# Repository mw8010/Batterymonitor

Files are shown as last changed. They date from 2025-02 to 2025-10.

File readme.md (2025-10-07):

# Battery Monitor with INA226 and SenseESP

## Overview
This project is a DIY battery monitor for our trawler. It uses an ESP32 to measure current, voltage, and power with the INA226 sensor. The collected data is integrated into Signal K via SenseESP. Additionally, a OneWire temperature sensor is used to monitor battery temperature.

## Why Low-Side Current Sensing?

Low-side current sensing means placing the shunt resistor between the negative battery terminal and ground (system GND). This method is recommended for higher battery voltages (e.g. 48V), as it keeps the INA226 within its voltage specifications and avoids damage or incorrect measurements.

**Advantages:**
- The INA226 always operates within its safe voltage range (max. 36V common-mode).
- Simple and safe wiring for most installations (vehicles, boats).
- No need for a voltage divider at the INA226 input.

**Note:**  
The measured current may have an inverted sign. This is corrected in the software.

## What is Signal K?
[Signal K](https://signalk.org/) is an open data format for marine electronics. It enables the integration and exchange of sensor data between various devices and applications on board a boat.

## What is SenseESP?
[SenseESP](https://github.com/SignalK/SensESP) is an open-source framework that simplifies the development of sensors that transmit their data to a Signal K server via Wi-Fi. It is based on the ESP32 and uses a modular architecture for flexible customization.

## Features
- Measurement of battery voltage, current, and power with INA226
- Calculation of the state of charge (SoC) based on battery type and voltage
- Calculation of remaining amp-hours (Ah) and estimated runtime
- Configurable battery parameters via the SenseESP web UI
- Alarm notifications for shunt overvoltage, bus overvoltage, and power limits
- Temperature monitoring via a OneWire sensor (e.g., DS18B20)

## Hardware Requirements
- **ESP32 D1 Mini** – Microcontroller
- **INA226 CJMCU** – Current sensor
- **DS18B20** – Temperature sensor
- **3A Mini DC-DC Buck Step Down Converter** – Voltage converter
- **Shunt resistor** – For current measurement (adapted to the maximum current)

## Terminal Assignments
| Terminal | Label | Description |
|---|---|---|
| **U1** | Power IN | + / - (6 - 48V) |
| **U2** | Temperature Sensor | + / - / Data |
| **U4** | INA226 | VBUS / IN- / IN+ |

## Signal K Data Points
- `electrical.batteries.<battery_name>.voltage` – Battery voltage in V
- `electrical.batteries.<battery_name>.current` – Battery current in A
- `electrical.batteries.<battery_name>.power` – Battery power in W
- `electrical.batteries.<battery_name>.stateOfCharge` – State of charge in % (coulomb counting)
- `electrical.batteries.<battery_name>.stateOfCharge_voltageSoC` – State of charge based on voltage in %
- `electrical.batteries.<battery_name>.ampHours` – Remaining Ah
- `electrical.batteries.<battery_name>.timeToGo` – Remaining time in seconds
- `electrical.batteries.<battery_name>.temperature` – Battery temperature in °K
- `electrical.batteries.<battery_name>.alerts.shuntOverVoltage` – Alarm for shunt overvoltage
- `electrical.batteries.<battery_name>.alerts.busOverVoltage` – Alarm for bus overvoltage
- `electrical.batteries.<battery_name>.alerts.powerOverLimit` – Alarm for power limit exceeded

## Installation
### 1. Preparation
- Install PlatformIO (recommended)
  - [PlatformIO IDE for VSCode](https://platformio.org/install/ide?install=vscode)
  - [PlatformIO IDE for Atom](https://platformio.org/install/ide?install=atom)
  - [PlatformIO Core (CLI)](https://docs.platformio.org/en/latest/core/installation.html)
- Install required libraries:
  - [SignalK/SenseESP](https://github.com/SignalK/SensESP)
  - [sensesp/OneWire](https://github.com/PaulStoffregen/OneWire)
  - [INA226](https://github.com/RobTillaart/INA226)

### 2. Clone the repository
- Clone or download this repository to your local machine:
  ```sh
  git clone https://github.com/mw8010/Batteriemonitor.git
  cd Batteriemonitor
  ```

### 3. Upload the code
Open the project in PlatformIO.
Upload the code to your ESP32.

### 4. Configure SenseESP
After the first start, the ESP32 will open an access point.
Connect to the network and enter the Wi-Fi credentials (Wi-Fi password: thisisfine).
Use the SenseESP web UI to configure the battery (see Configuration) and connect the ESP32 to the network where the Signal K server is running.
The data should now appear on the Signal K server under the configured paths.

## Configuration
The following parameters can be adjusted via the SenseESP web UI:
- Battery type (LiFePO4, AGM, Gel, Lead-Acid)
- Battery voltage (12V, 24V, 48V (LiFePO4 only))
- Battery capacity in Ah
- Maximum shunt current
- Shunt voltage in mV
- Battery name for Signal K

**After each configuration change, the ESP32 must be restarted.**

## Usage
- Once set up, the ESP32 continuously transmits measurement values to Signal K.
- Configuration changes can be made via the web UI.
- Alarm notifications are triggered when defined thresholds are exceeded.

### Hardware Installation Notes
**Shunt Resistor (Low-Side Measurement)**

- The shunt resistor must be installed between the negative battery terminal and the system ground (GND).
- Connect the negative battery terminal to one end of the shunt resistor.
- Connect the other end of the shunt resistor to the system ground (GND).
- All consumers and the ESP32 remain connected to system ground as usual.
- Ensure that all connections are tight and secure to ensure accurate measurements.

**INA226 Sensor (Low-Side Wiring)**

- Connect the INA226 sensor to the shunt resistor according to the schematic:
  - `IN+` of the INA226 to the end of the shunt connected to the negative battery terminal.
  - `IN-` of the INA226 to the end of the shunt connected to system ground (GND).
  - `VBUS` connected to system ground (GND).
- Connect the INA226 sensor to the ESP32 according to the schematic.

**ESP32**

- Connect the ESP32 to the INA226 sensor and the OneWire temperature sensor according to the schematic.
- Ensure that the ESP32 is properly powered (e.g., via a DC-DC Buck Step Down Converter).

**PCB**

- To facilitate the connection of the components, you can use the Gerber files in the gerber folder to order a suitable PCB.

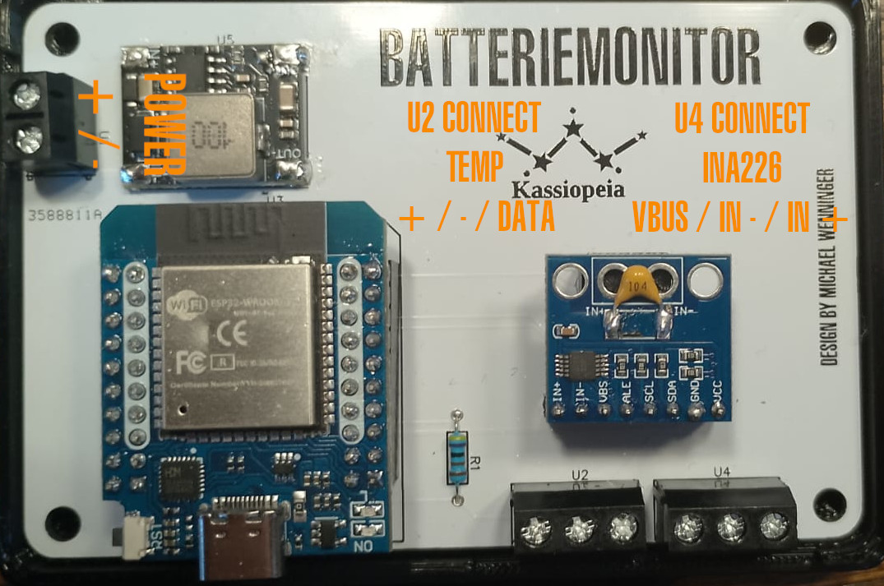
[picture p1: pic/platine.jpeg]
PCB


### Enclosure

In the `/3d-files` folder, you will find STEP files for a suitable enclosure that you can print to protect and mount the finished PCB.

## Used Components
- [ESP32 D1 Mini](https://de.aliexpress.com/item/1005006267267848.html)
- [INA226 CJMCU](https://de.aliexpress.com/item/1005001972537281.html)
- [3A Mini DC-DC Buck Step Down Converter](https://de.aliexpress.com/item/1005005505907937.html)
- [DS18B20 Temperature Sensor](https://de.aliexpress.com/item/1005005488542048.html)

## Repository Files
- **`/gerber`** – Contains Gerber files for the PCB.
- **`/schematic`** – Contains the circuit diagram.
- **`/3d-files`** – Contains the STEP files for a suitable enclosure.

## License
- **Software:** [GNU General Public License v3.0](license.md)  
- **Hardware:** [CERN Open Hardware Licence v2 - Strongly Reciprocal](license.md)

## Acknowledgments
This project is based on the [Battery Monitor Project by Techstyleuk](https://github.com/Techstyleuk/SensESP_3_Battery_Monitor).

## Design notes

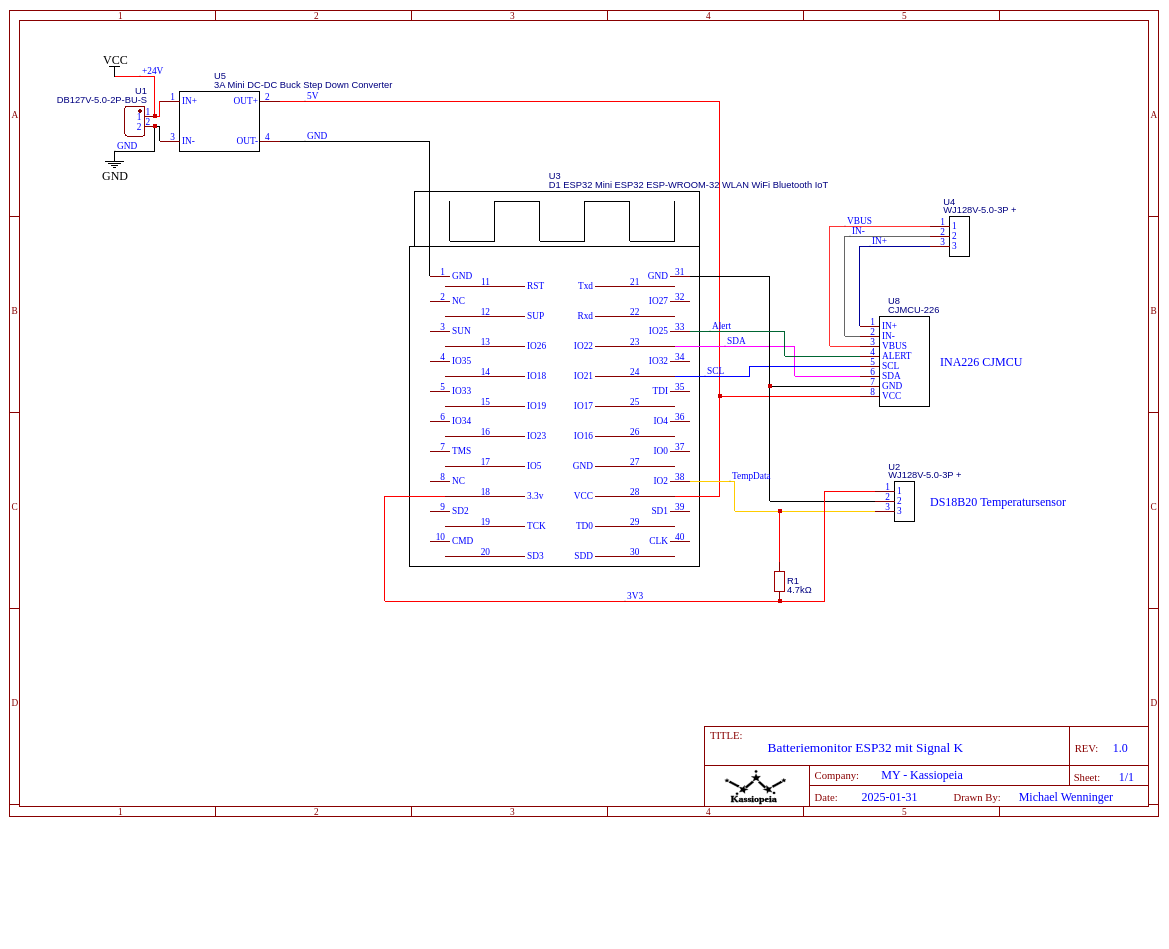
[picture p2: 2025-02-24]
schaltplan/Schematic_Batteriemonitor_2025-02-23.png

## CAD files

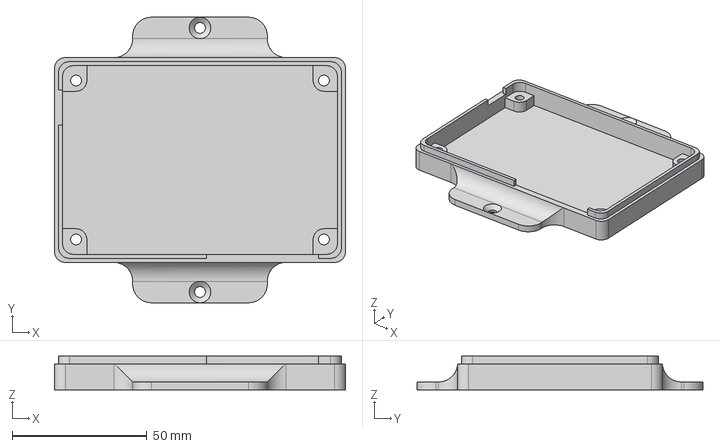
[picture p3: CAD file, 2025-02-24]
3d-files/Boden.step
108.0 x 106.0 x 12.6 mm

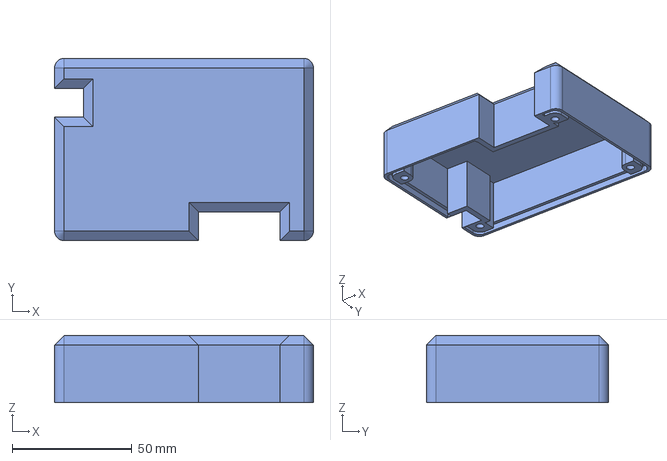
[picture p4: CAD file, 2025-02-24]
3d-files/Deckel.step
108.0 x 76.0 x 28.0 mm

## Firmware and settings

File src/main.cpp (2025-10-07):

#include <Arduino.h>
#include <memory>
#include "sensesp/signalk/signalk_output.h"
#include "sensesp/transforms/linear.h"
#include "sensesp/transforms/curveinterpolator.h"
#include "sensesp/ui/config_item.h"
#include "sensesp/ui/ui_controls.h"
#include "sensesp_app_builder.h"
#include "sensesp_onewire/onewire_temperature.h"
#include "sensesp/signalk/signalk_metadata.h"
#include "INA226.h"

using namespace sensesp;
using namespace sensesp::onewire;

// Setze die INA226-Adresse
INA226 INA0(0x40);

// Setze Wifi-Netzwerkdaten
const char* hostname = "BatteryShuntESP";

// Variable Temperatursensor
uint8_t pin = 2; // Pin, an dem der Temperatursensor angeschlossen ist

// Abfrageintervall für die Sensoren
uint read_delay = 1000; // Zeit zwischen den Messungen

// Globale Variablen für Batterietyp, Spannung und AH
String battery_type = "LiFePO4"; // Standardtyp der Batterie
String battery_type_config_path = "/config/battery_type";
float battery_voltage = 12; // Standardspannung der Batterie in V
String battery_voltage_config_path = "/config/battery_voltage";
float battery_capacity = 100; // Standardkapazität der Batterie in Ah
String battery_capacity_config_path = "/config/battery_ah";

// Konfigurationspfade für den INA226
float max_current = 500.0; // Maximalstrom in A
String max_current_config_path = "/config/max_current";
float shunt_voltage = 75.0; // Shunt-Spannung in mV
String shunt_voltage_config_path = "/config/shunt_voltage";
float shunt_resistance; // Shunt-Widerstand in Ohm (Wert wird berechnet)
String shunt_resistance_config_path = "/config/shunt_resistance";

// Definiere Variable für den Batterienamen
String battery_name = "Battery1"; // Standardname für die Batterie
String battery_name_config_path = "/config/battery_name";

// Erstelle den vollständigen SignalK Pfad durch Konkatenation
String sk_path_current = "electrical.batteries." + battery_name + ".current";
String sk_path_voltage = "electrical.batteries." + battery_name + ".voltage";
String sk_path_power = "electrical.batteries." + battery_name + ".power";
String sk_path_soc = "electrical.batteries." + battery_name + ".stateOfCharge";
String sk_path_ah = "electrical.batteries." + battery_name + ".ampHours";
String sk_path_time_to_go = "electrical.batteries." + battery_name + ".timeToGo";
String sk_path_shunt_over_voltage = "electrical.batteries." + battery_name + ".alerts.shuntOverVoltage";
String sk_path_bus_over_voltage = "electrical.batteries." + battery_name + ".alerts.busOverVoltage";
String sk_path_power_over_limit = "electrical.batteries." + battery_name + ".alerts.powerOverLimit";
String temp_one_wire_path = "/Battery Temperature/" + battery_name + "/oneWire";
String temp_linear_path = "/Battery Temperature/" + battery_name + "/linear";
String temp_sk_path = "electrical.batteries." + battery_name + ".temperature";

//Definiere die Metadaten für die SignalK-Objekte
SKMetadata* metadata_current = new SKMetadata("A", "Current", "Current of the battery", "A");
SKMetadata* metadata_voltage = new SKMetadata("V", "Voltage", "Voltage of the battery", "V");
SKMetadata* metadata_power = new SKMetadata("W", "Power", "Power of the battery", "W");
SKMetadata* metadata_soc = new SKMetadata("%", "State of Charge", "State of Charge of the battery", "%");
SKMetadata* metadata_ah = new SKMetadata("Ah", "Ampere Hours", "Ampere Hours used of the battery", "Ah");
SKMetadata* metadata_time_to_go = new SKMetadata("s", "Time to Go", "Time to go of the battery", "s");
SKMetadata* metadata_shunt_over_voltage = new SKMetadata("Alert", "Shunt Over Voltage", "Shunt Over Voltage Alert", "Alert");
SKMetadata* metadata_bus_over_voltage = new SKMetadata("Alert", "Bus Over Voltage", "Bus Over Voltage Alert", "Alert");
SKMetadata* metadata_power_over_limit = new SKMetadata("Alert", "Power Over Limit", "Power Over Limit Alert", "Alert");
SKMetadata* metadata_temp = new SKMetadata("K", "Temperature", "Temperature of the battery", "K");

// Definiere Variablen für die Alarmmeldungen
SKOutputString* alert_shunt_over_voltage;
SKOutputString* alert_bus_over_voltage;
SKOutputString* alert_power_over_limit;

// Variable für verbrauchte Amperestunden
float amp_hours_used = 0.0;

// Berechne den Shunt-Widerstand basierend auf dem maximalen Strom und der Spannung
float calculateShuntResistance(float max_current, float shunt_voltage) {
    return shunt_voltage / max_current;
}

// SOCA-Interpreter Klasse
class SoCAInterpreter : public CurveInterpolator {
    public:
        SoCAInterpreter(String battery_type, float system_voltage, String config_path = "")
            : CurveInterpolator(NULL, config_path) {

        clear_samples();
        if (system_voltage == 12 && battery_type == "LiFePO4") {
            add_sample(CurveInterpolator::Sample(10.0, 0.0)); // 0%
            add_sample(CurveInterpolator::Sample(11.4, 0.1)); // 10%
            add_sample(CurveInterpolator::Sample(11.6, 0.2)); // 20%
            add_sample(CurveInterpolator::Sample(11.8, 0.3)); // 30%
            add_sample(CurveInterpolator::Sample(12.0, 0.4)); // 40%
            add_sample(CurveInterpolator::Sample(12.4, 0.5)); // 50%
            add_sample(CurveInterpolator::Sample(12.8, 0.6)); // 60%
            add_sample(CurveInterpolator::Sample(13.2, 0.7)); // 70%
            add_sample(CurveInterpolator::Sample(13.6, 0.8)); // 80%
            add_sample(CurveInterpolator::Sample(14.0, 0.9)); // 90%
            add_sample(CurveInterpolator::Sample(14.6, 1.0)); // 100%
        } else if (system_voltage == 24 && battery_type == "LiFePO4") {
            add_sample(CurveInterpolator::Sample(20.0, 0.0)); // 0%
            add_sample(CurveInterpolator::Sample(22.8, 0.1)); // 10%
            add_sample(CurveInterpolator::Sample(23.2, 0.2)); // 20%
            add_sample(CurveInterpolator::Sample(23.6, 0.3)); // 30%
            add_sample(CurveInterpolator::Sample(24.0, 0.4)); // 40%
            add_sample(CurveInterpolator::Sample(24.8, 0.5)); // 50%
            add_sample(CurveInterpolator::Sample(25.6, 0.6)); // 60%
            add_sample(CurveInterpolator::Sample(26.4, 0.7)); // 70%
            add_sample(CurveInterpolator::Sample(27.2, 0.8)); // 80%
            add_sample(CurveInterpolator::Sample(28.0, 0.9)); // 90%
            add_sample(CurveInterpolator::Sample(29.2, 1.0)); // 100%
        } else if (system_voltage == 48 && battery_type == "LiFePO4") {
            add_sample(CurveInterpolator::Sample(48.0, 0.0));  // 0% (3.00V/Zelle)
            add_sample(CurveInterpolator::Sample(48.8, 0.1));  // 10%
            add_sample(CurveInterpolator::Sample(49.6, 0.2));  // 20%
            add_sample(CurveInterpolator::Sample(50.4, 0.3));  // 30%
            add_sample(CurveInterpolator::Sample(51.2, 0.4));  // 40%
            add_sample(CurveInterpolator::Sample(52.0, 0.5));  // 50%
            add_sample(CurveInterpolator::Sample(52.8, 0.6));  // 60%
            add_sample(CurveInterpolator::Sample(53.6, 0.7));  // 70%
            add_sample(CurveInterpolator::Sample(54.0, 0.8));  // 80%
            add_sample(CurveInterpolator::Sample(54.2, 0.9));  // 90%
            add_sample(CurveInterpolator::Sample(54.4, 1.0));  // 100% (3.40V/Zelle)
        } else if (system_voltage == 12 && battery_type == "AGM") {
            add_sample(CurveInterpolator::Sample(10.5, 0.0)); // 0%
            add_sample(CurveInterpolator::Sample(11.0, 0.1)); // 10%
            add_sample(CurveInterpolator::Sample(11.2, 0.2)); // 20%
            add_sample(CurveInterpolator::Sample(11.4, 0.3)); // 30%
            add_sample(CurveInterpolator::Sample(11.6, 0.4)); // 40%
            add_sample(CurveInterpolator::Sample(11.8, 0.5)); // 50%
            add_sample(CurveInterpolator::Sample(12.0, 0.6)); // 60%
            add_sample(CurveInterpolator::Sample(12.2, 0.7)); // 70%
            add_sample(CurveInterpolator::Sample(12.4, 0.8)); // 80%
            add_sample(CurveInterpolator::Sample(12.6, 0.9)); // 90%
            add_sample(CurveInterpolator::Sample(12.8, 1.0)); // 100%
        } else if (system_voltage == 24 && battery_type == "AGM") {
            add_sample(CurveInterpolator::Sample(21.0, 0.0)); // 0%
            add_sample(CurveInterpolator::Sample(22.0, 0.1)); // 10%
            add_sample(CurveInterpolator::Sample(22.4, 0.2)); // 20%
            add_sample(CurveInterpolator::Sample(22.8, 0.3)); // 30%
            add_sample(CurveInterpolator::Sample(23.2, 0.4)); // 40%
            add_sample(CurveInterpolator::Sample(23.6, 0.5)); // 50%
            add_sample(CurveInterpolator::Sample(24.0, 0.6)); // 60%
            add_sample(CurveInterpolator::Sample(24.4, 0.7)); // 70%
            add_sample(CurveInterpolator::Sample(24.8, 0.8)); // 80%
            add_sample(CurveInterpolator::Sample(25.2, 0.9)); // 90%
            add_sample(CurveInterpolator::Sample(25.6, 1.0)); // 100%
        } else if (system_voltage == 12 && battery_type == "Gel") {
            add_sample(CurveInterpolator::Sample(10.5, 0.0)); // 0%
            add_sample(CurveInterpolator::Sample(11.4, 0.1)); // 10%
            add_sample(CurveInterpolator::Sample(11.6, 0.2)); // 20%
            add_sample(CurveInterpolator::Sample(11.75, 0.3));// 30%
            add_sample(CurveInterpolator::Sample(11.9, 0.4)); // 40%
            add_sample(CurveInterpolator::Sample(12.0, 0.5)); // 50%
            add_sample(CurveInterpolator::Sample(12.2, 0.6)); // 60%
            add_sample(CurveInterpolator::Sample(12.35, 0.7));// 70%
            add_sample(CurveInterpolator::Sample(12.5, 0.8)); // 80%
            add_sample(CurveInterpolator::Sample(12.7, 0.9)); // 90%
            add_sample(CurveInterpolator::Sample(12.9, 1.0)); // 100%   
        } else if (system_voltage == 24 && battery_type == "Gel") {
            add_sample(CurveInterpolator::Sample(21.0, 0.0)); // 0%
            add_sample(CurveInterpolator::Sample(22.8, 0.1)); // 10%
            add_sample(CurveInterpolator::Sample(23.2, 0.2)); // 20%
            add_sample(CurveInterpolator::Sample(23.5, 0.3)); // 30%
            add_sample(CurveInterpolator::Sample(23.8, 0.4)); // 40%
            add_sample(CurveInterpolator::Sample(24.0, 0.5)); // 50%
            add_sample(CurveInterpolator::Sample(24.4, 0.6)); // 60%
            add_sample(CurveInterpolator::Sample(24.7, 0.7)); // 70%
            add_sample(CurveInterpolator::Sample(25.0, 0.8)); // 80%
            add_sample(CurveInterpolator::Sample(25.4, 0.9)); // 90%
            add_sample(CurveInterpolator::Sample(25.8, 1.0)); // 100%
        } else if (system_voltage == 12 && battery_type == "Lead Acid"){
            add_sample(CurveInterpolator::Sample(10.5, 0.0)); // 0%
            add_sample(CurveInterpolator::Sample(11.2, 0.1)); // 10%
            add_sample(CurveInterpolator::Sample(11.4, 0.2)); // 20%
            add_sample(CurveInterpolator::Sample(11.6, 0.3)); // 30%
            add_sample(CurveInterpolator::Sample(11.7, 0.4)); // 40%
            add_sample(CurveInterpolator::Sample(11.9, 0.5)); // 50%
            add_sample(CurveInterpolator::Sample(12.0, 0.6)); // 60%
            add_sample(CurveInterpolator::Sample(12.2, 0.7)); // 70%
            add_sample(CurveInterpolator::Sample(12.3, 0.8)); // 80%
            add_sample(CurveInterpolator::Sample(12.5, 0.9)); // 90%
            add_sample(CurveInterpolator::Sample(12.7, 1.0)); // 100%
        } else if (system_voltage == 24 && battery_type == "Lead Acid"){
            add_sample(CurveInterpolator::Sample(21.0, 0.0)); // 0%
            add_sample(CurveInterpolator::Sample(22.4, 0.1)); // 10%
            add_sample(CurveInterpolator::Sample(22.8, 0.2)); // 20%
            add_sample(CurveInterpolator::Sample(23.2, 0.3)); // 30%
            add_sample(CurveInterpolator::Sample(23.4, 0.4)); // 40%
            add_sample(CurveInterpolator::Sample(23.8, 0.5)); // 50%
            add_sample(CurveInterpolator::Sample(24.0, 0.6)); // 60%
            add_sample(CurveInterpolator::Sample(24.4, 0.7)); // 70%
            add_sample(CurveInterpolator::Sample(24.6, 0.8)); // 80%
            add_sample(CurveInterpolator::Sample(25.0, 0.9)); // 90%
            add_sample(CurveInterpolator::Sample(25.4, 1.0)); // 100%
        }
    }
};

//Globale Variable für den SoC-Interpreter
std::unique_ptr<SoCAInterpreter> soc_interpolator; // SoC-Interpreter für die Batterie

void setupBattery() {
    // Konfiguriere, SesEsp WebUi für die Batteriewahl
    auto battery_type_config = std::make_shared<StringConfig>(battery_type, battery_type_config_path);
    auto battery_voltage_config = std::make_shared<NumberConfig>(battery_voltage, battery_voltage_config_path);
    auto battery_capacity_config = std::make_shared<NumberConfig>(battery_capacity, battery_capacity_config_path);
    auto max_current_config = std::make_shared<NumberConfig>(max_current, max_current_config_path);
    auto shunt_voltage_config = std::make_shared<NumberConfig>(shunt_voltage, shunt_voltage_config_path);
    auto battery_name_config = std::make_shared<StringConfig>(battery_name, battery_name_config_path);
    

    ConfigItem(battery_type_config)
        ->set_title("Battery Type")
        ->set_description("LiFePO4, AGM, Gel, Lead Acid")
        ->set_sort_order(100);
    ConfigItem(battery_voltage_config)
        ->set_title("Battery Voltage")
        ->set_description("12V, 24V, 48V (only LiFePO4 supported)")
        ->set_sort_order(200);
    ConfigItem(battery_capacity_config)
        ->set_title("Battery Capacity (Ah)")
        ->set_sort_order(300);
    ConfigItem(max_current_config)
        ->set_title("Shunt Current (A)")
        ->set_sort_order(400); 
    ConfigItem(shunt_voltage_config)
        ->set_title("Shunt Voltage (mV)")
        ->set_sort_order(500);
    ConfigItem(battery_name_config)
        ->set_title("Battery Name")
        ->set_description("Name of the Battery for Signal K Path (eg. House, Starter, etc.)")
        ->set_sort_order(600); 

    // Lade die Konfigurationswerte der Batterie
    battery_type = battery_type_config->get_value();
    battery_voltage = battery_voltage_config->get_value();
    battery_capacity = battery_capacity_config->get_value();
    max_current = max_current_config->get_value();
    shunt_voltage = shunt_voltage_config->get_value() / 1000.0;
    battery_name = battery_name_config->get_value();

    // Aktualisiere die SignalK-Pfade basierend auf den geladenen Konfigurationswerten
    sk_path_current = "electrical.batteries." + battery_name + ".current";
    sk_path_voltage = "electrical.batteries." + battery_name + ".voltage";
    sk_path_power = "electrical.batteries." + battery_name + ".power";
    sk_path_soc = "electrical.batteries." + battery_name + ".stateOfCharge";
    sk_path_ah = "electrical.batteries." + battery_name + ".ampHours";
    sk_path_time_to_go = "electrical.batteries." + battery_name + ".timeToGo";
    sk_path_shunt_over_voltage = "electrical.batteries." + battery_name + ".alerts.shuntOverVoltage";
    sk_path_bus_over_voltage = "electrical.batteries." + battery_name + ".alerts.busOverVoltage";
    sk_path_power_over_limit = "electrical.batteries." + battery_name + ".alerts.powerOverLimit";
    temp_one_wire_path = "/Battery Temperature/" + battery_name + "/oneWire";
    temp_linear_path = "/Battery Temperature/" + battery_name + "/linear";
    temp_sk_path = "electrical.batteries." + battery_name + ".temperature";
    

    // Berechne den Shunt-Widerstand basierend auf dem maximalen Strom und der Spannung
    shunt_resistance = calculateShuntResistance(max_current, shunt_voltage);

    // Erstelle den SoC-Interpreter mit den geladenen Konfigurationswerten
    soc_interpolator.reset(new SoCAInterpreter(battery_type, battery_voltage));    
}

// Hilfsfunktion: 100%-Spannung aus CurveInterpolator
float getFullVoltage() {
    auto& samples = soc_interpolator->get_samples();
    if (!samples.empty()) {
        return std::prev(samples.end())->input_; // Letzter Eintrag ist 100%
    }
    return 0.0; // Rückgabe 0, wenn keine Samples vorhanden sind
}

float shunt_over_voltage_limit = max_current * shunt_resistance * 1000;
float bus_over_voltage_limit = battery_voltage * 1000;
float power_over_limit = battery_voltage * max_current;

// Initialisiere den INA226
void initINA226() {
    INA0.begin();
    INA0.setAverage(INA226_64_SAMPLES);
    INA0.setBusVoltageConversionTime(INA226_1100_us);
    INA0.setShuntVoltageConversionTime(INA226_1100_us);
    INA0.setMode(7);
    INA0.setMaxCurrentShunt(max_current, shunt_resistance); // Kalibriere den INA226 Sensor (Maximalstrom und Shunt-Widerstand)

    // Konfiguriere INA226 für den Alarm
    INA0.setAlertRegister(INA226_SHUNT_OVER_VOLTAGE | INA226_BUS_OVER_VOLTAGE | INA226_POWER_OVER_LIMIT);

    //Setze die Limits für die Alarme basierend auf den Konfigurationswerten
    INA0.setAlertLimit(bus_over_voltage_limit); // Setze den Bus-Überspannungsalarm
    INA0.setAlertLimit(shunt_over_voltage_limit); // Setze den Shunt-Überspannungsalarm
    INA0.setAlertLimit(power_over_limit); // Setze den Leistungsüberschreitungsalarm
}

float read_INA0_current_callback(){
    return -INA0.getCurrent();
}
float read_INA0_voltage_callback(){
    return INA0.getBusVoltage();
}
float read_INA0_power_callback(){
    return INA0.getPower();
}

float calculateSoC(float amp_hours_used, float battery_capacity) {
    return ((battery_capacity - amp_hours_used) / battery_capacity) * 100;
}

float calculateAmpHours(float current, float time_seconds) {
    return current * (time_seconds / 3600);
}
float total_amp_hours = 0;
unsigned long last_time = 0;

void updateAmpHours() {
    unsigned long current_time = millis();
    float time_diff = (current_time - last_time) / 1000.0;
    float current = INA0.getCurrent();
    float voltage = INA0.getBusVoltage();

    // Automatischer Reset, wenn Batteriespannung >= 100% (mit Toleranz)
    float full_voltage = getFullVoltage();
    if (full_voltage > 0.0 && voltage >= (full_voltage - 0.05)) { // 0.05V Toleranz
        total_amp_hours = 0; // Setze die verbrauchten Ampere-Stunden zurück
        amp_hours_used = 0; // Setze die verbrauchten Ampere-Stunden zurück
    }
    total_amp_hours += calculateAmpHours(current, time_diff);
    amp_hours_used = total_amp_hours; // Aktualisiere die verbrauchten Ampere-Stunden
    last_time = current_time; // Aktualisiere die letzte Zeit
}

float calculateTimeToGo(float current, float amp_hours_used) {
    if (current == 0) {
        return INFINITY; // Wenn der Strom 0 ist, wird unendlich zurückgegeben
    }
    return (battery_capacity - amp_hours_used) / current;
}

void IRAM_ATTR handle_Alert() {
    uint16_t alertflag = INA0.getAlertFlag();
    if (alertflag & INA226_SHUNT_OVER_VOLTAGE) {
        alert_shunt_over_voltage->set("Shunt Over Voltage");
    }
    if (alertflag & INA226_BUS_OVER_VOLTAGE) {
        alert_bus_over_voltage->set("Bus Over Voltage");
    }
    if (alertflag & INA226_POWER_OVER_LIMIT) {
        alert_power_over_limit->set("Power Over Limit");
    }
}
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
void loop() {
    event_loop()->tick();
}

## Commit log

2025-02-24 Füge neue Dateien für das Projekt hinzu: Bilder, Konfigurationsdateien, README-Dokumente und Lizenzinformationen
    [Boden.step, Deckel.step, min_spiffs.csv]
2025-02-24 Aktualisiere README-Dokumente mit Installationsanweisungen, Hardware-Installationshinweisen und neuen Informationen zu Gehäuse und Platine
2025-02-24 Aktualisiere README-Dokumente: Verschiebe und strukturiere Abschnitte zur High-Side-Strommessung und Signal K
2025-02-24 Kommentiere I2C-Pins und Alarm-Pin im Setup, um die Lesbarkeit zu verbessern
2025-02-24 Aktualisiere Verweise auf den Ordner für STEP-Dateien im README und README_DE, um die Konsistenz zu verbessern.
2025-02-24 Aktualisiere den Klon-Link im README und README_DE auf den neuen Benutzernamen für Konsistenz
2025-02-24 Aktualisiere Lizenzverweise im README auf die neuen Dateinamen für Konsistenz
2025-06-02 Verbessere den SoC-Interpreter und aktualisiere die Sensorabfrageintervalle für bessere Lesbarkeit und Funktionalität
2025-06-02 Bewege die globale Variable für den SoC-Interpreter nach oben und verbessere die Lesbarkeit der Rückgabewerte in der Funktion getFullVoltage.
2025-06-02 Aktualisiere README und README_DE mit zusätzlichen Informationen zum Ladezustand und zur Batteriespannung für bessere Klarheit und Konsistenz.
2025-10-07 Korrigiere das Vorzeichen des aktuellen Wertes im INA226-Callback für genaue Messungen.
    [main.cpp]
